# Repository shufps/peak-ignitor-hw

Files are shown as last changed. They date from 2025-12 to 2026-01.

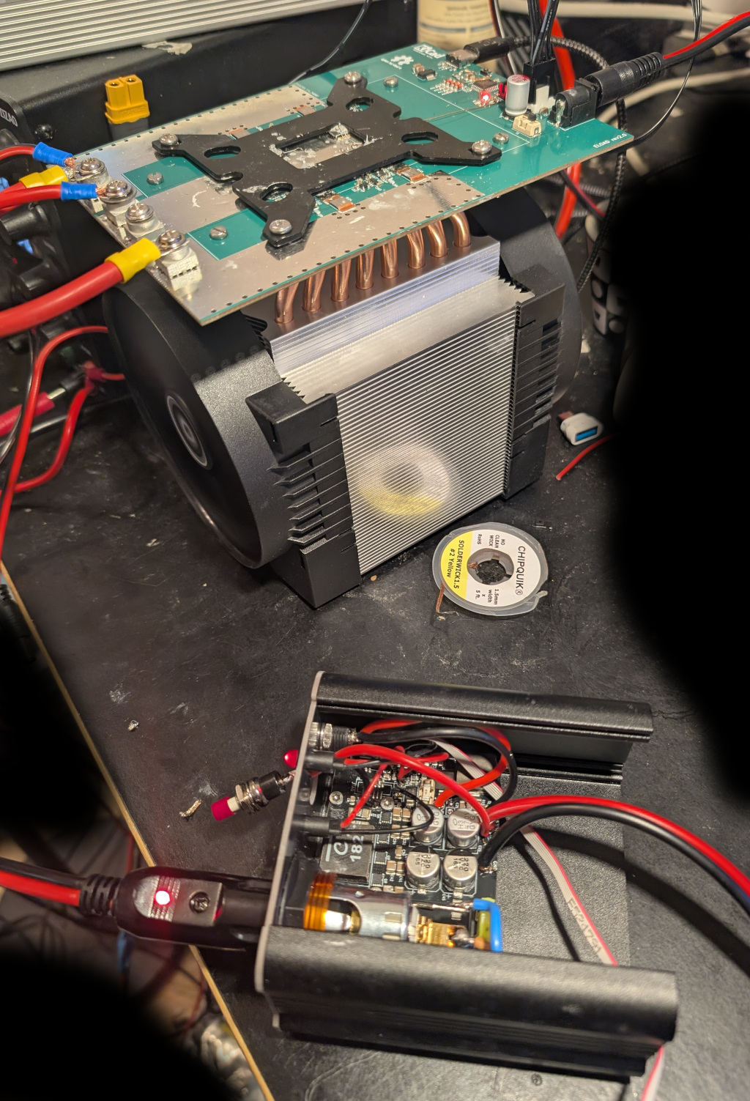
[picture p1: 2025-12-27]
images/load-test.jpg

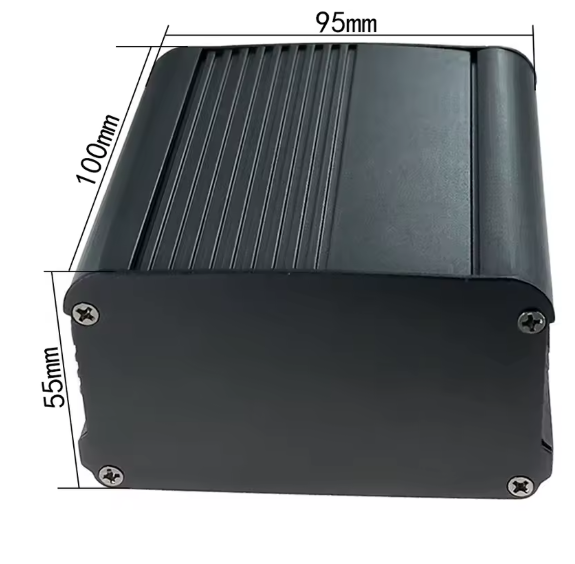
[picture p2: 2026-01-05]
bom/case.png

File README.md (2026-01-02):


> 🚧 **Work in Progress**  
> This project is under active development.

# 🔥 Peak Ignitor

**Peak Ignitor** is a compact, battery-powered **high-power 12 V supply** designed for one very specific real-world problem:

> *Reliable power in cold, wind, and harsh environments.*

The original trigger was simple:  
lighting a cigarette on a mountain at –10 °C and strong wind — where gas, electric, and plasma lighters all failed.

What *did* work was a classic **car cigarette lighter**:  
wind-proof, temperature-independent, and brutally simple — as long as you can supply enough current.

That requirement immediately defines the problem space:

- 6–10 A at 12 V  
- ~120 W continuous power  
- short but demanding duty cycles  

Peak Ignitor is the result.

---






## What It Is

Peak Ignitor is a **hand-sized, self-contained 12 V power unit** capable of delivering **120 W continuously** (up to ~160 W peak), powered by a **4S Li-Ion battery pack** and designed with **thermal and mechanical constraints as first-class design inputs**.

This is not a power bank and not a jump starter — it sits deliberately in between.

---

## Key Characteristics

- 🔋 **4S Li-Ion Battery System**
  - 4S1P Samsung 18650 (30Q)
  - ~44 Wh energy
  - Proper BMS with balancing and protection
  - Battery operated close to practical limits — intentionally and transparently

- ⚡ **Regulated 12 V Output**
  - High-power buck/boost converter (TI LM51770)
  - ~120 W continuous output
  - ~160 W peak, time-limited
  - Standard automotive cigarette lighter socket

- 🧊 **Mechanics-First Thermal Design**
  - Custom-machined **solid copper heatsink**
  - Direct thermal coupling into the aluminum enclosure
  - The enclosure itself acts as a secondary heatsink
  - Temperature measurement placed directly beneath the heatsink (TMP1075)

- 🧠 **Embedded Control & Monitoring**
  - ESP32-S3 Mini-1
  - Real-time monitoring of voltage, current, power, and temperature
  - Software-enforced safety limits (not just hardware ceilings)
  - Wi-Fi Web UI for observability (because why not 😎)

- 🔌 **Integrated Charging**
  - Onboard Li-Ion charging circuit
  - Balancer connector
  - Fully self-contained — no external hobby charger required

---

## Design Approach

A central idea behind Peak Ignitor is **mechanics-first design**:

The complete 3D model — enclosure, PCB outline, mounting points, heatsink geometry, connector placement, and thermal paths — was created **before** PCB layout and component selection.

This tightly couples:

- Mechanical design  
- PCB layout and form factor  
- Thermal constraints  
- User interaction and front-panel layout  

into a single coherent system.

As a result, the PCB, heatsink, battery pack, and enclosure are not independent parts — they are **co-designed elements of one integrated structure**.

---

## Thermal Philosophy

Thermal management is not an accessory here.

Heat is transferred:
1. from the power electronics  
2. into a custom copper heatsink  
3. directly into the aluminum enclosure  

This effectively turns the entire case into an active thermal component — a design style commonly found in industrial or automotive hardware, but rarely in DIY projects.

Sustained output is **intentionally limited by battery temperature**, not by electronic capability.

---

## Typical Use Cases

- 🔥 **Car cigarette lighter**  
  6–10 A for seconds — trivial load.

- 🏄 **SUP pumps / small compressors**  
  ~110 W continuous at 12 V.

- ⛏️ **NerdQAxe++**  
  ~80 W mobile operation.

- 🔌 **General 12 V loads**  
  Measurement equipment, adapters, field hardware.

---

## What This Project Demonstrates

Peak Ignitor is less about lighting a cigarette — and more about showing what happens when:

- real-world requirements  
- harsh environmental constraints  
- and a refusal to accept “almost good enough”  

meet a **system-level engineering mindset**.

It combines:
- energy storage  
- power electronics  
- thermal engineering  
- mechanical design  
- embedded firmware  

into a compact, honest, high-power device.

---

## Notes

- High-current device — **not a toy**
- Use only suitable loads
- Do not bypass or modify protection mechanisms
- Never operate the battery without the BMS

---

> *A good horse jumps only as high as it needs to.*  
> **Peak Ignitor jumps higher — on purpose.**

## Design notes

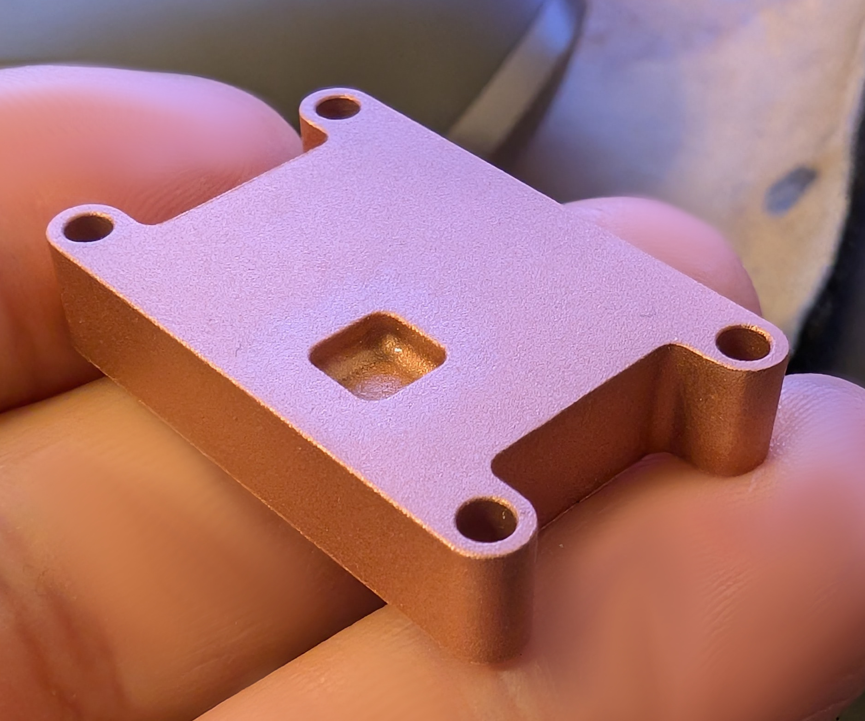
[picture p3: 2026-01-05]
images/heatsink.jpg

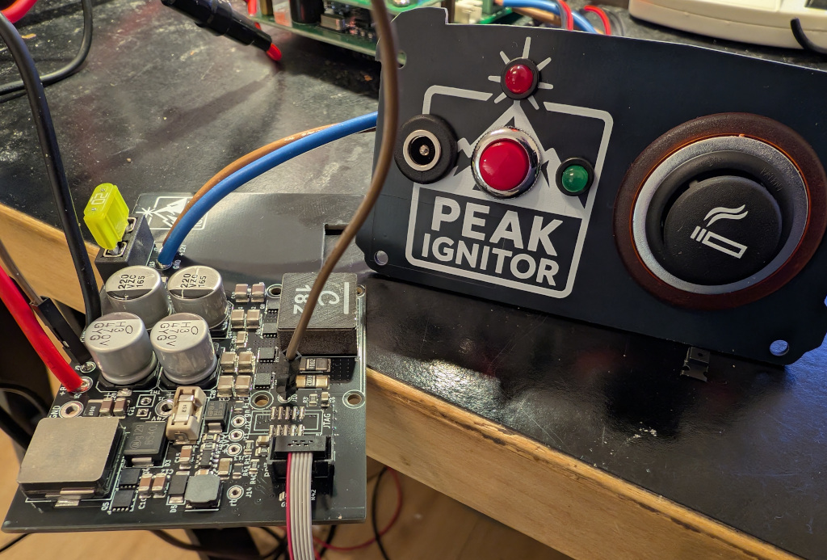
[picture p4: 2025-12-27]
images/pcb-top.jpg

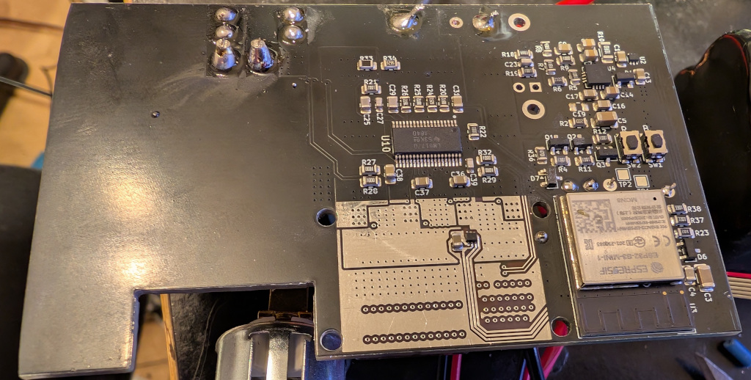
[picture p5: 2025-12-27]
images/pcb-bottom.jpg

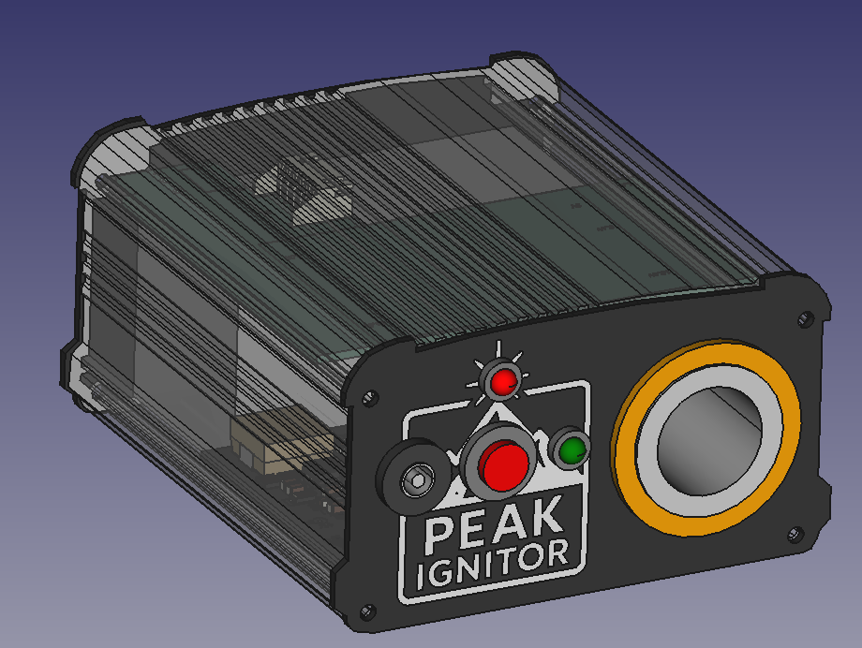
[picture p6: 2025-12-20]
images/case-3d-render.png

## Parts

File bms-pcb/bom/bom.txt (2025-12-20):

- XT30-PW-M (eg ebay)
- S5B-XH-A-1 (eg Aliexpress)
- BMS 4s PCB like in the picture

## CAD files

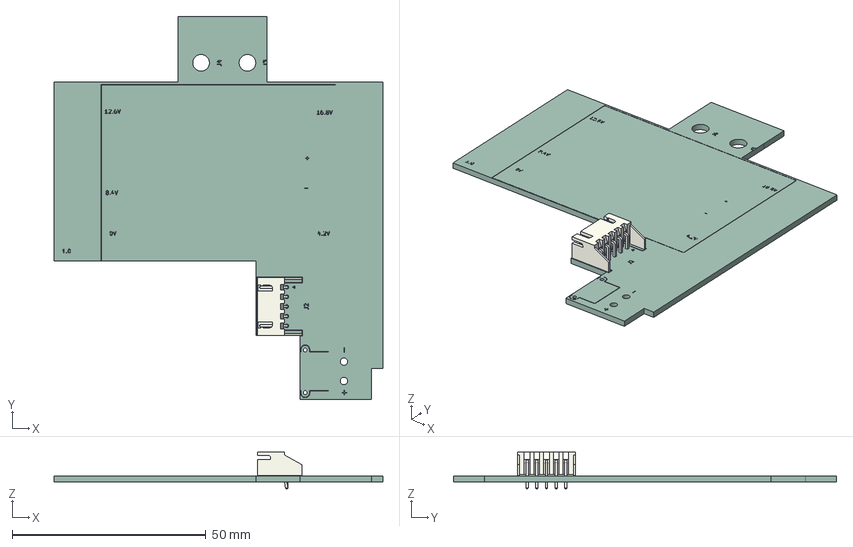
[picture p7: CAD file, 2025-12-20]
bms-pcb/kicad/peak-ignitor-box-bms.step
85.0 x 99.0 x 9.50 mm
JST_XH_S5B-XH-A-1_1x05_P2.50mm_Horizontal
peak-ignitor-box-bms_silkscreen
peak-ignitor-box-bms_PCB

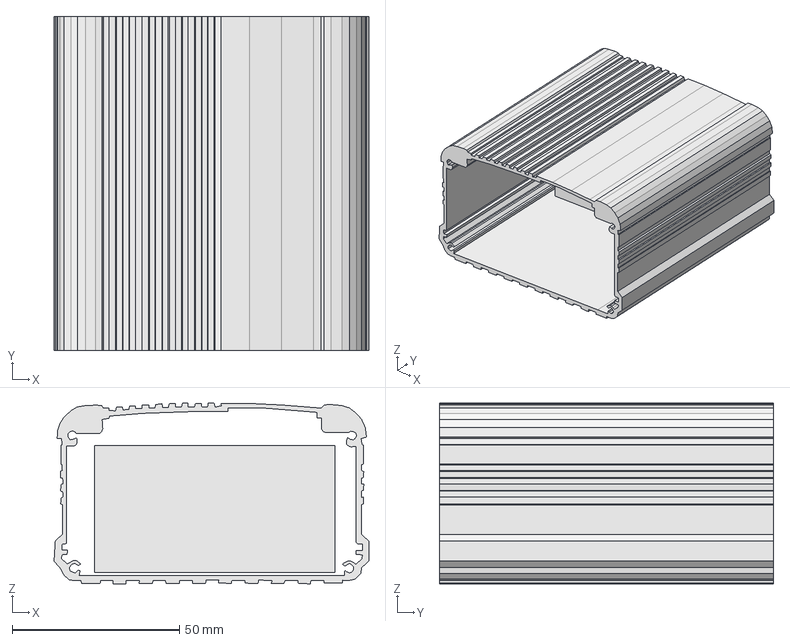
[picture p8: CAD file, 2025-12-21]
case/case.FCStd
94.3 x 100.0 x 54.2 mm

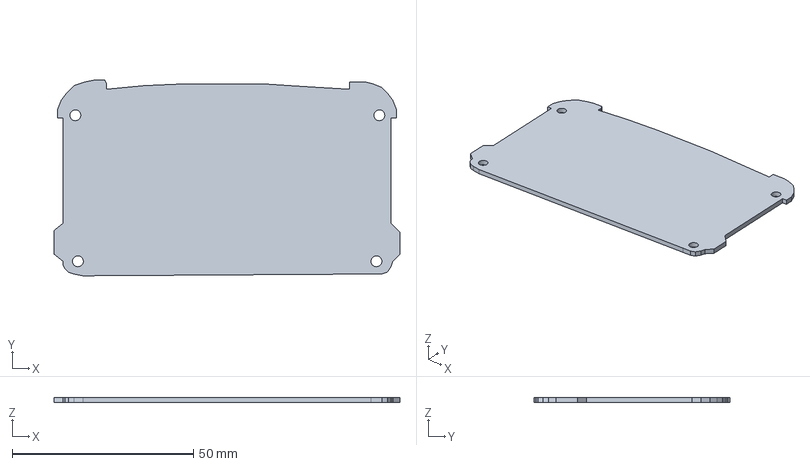
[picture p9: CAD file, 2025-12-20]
kicad/back.step
95.5 x 54.0 x 1.51 mm

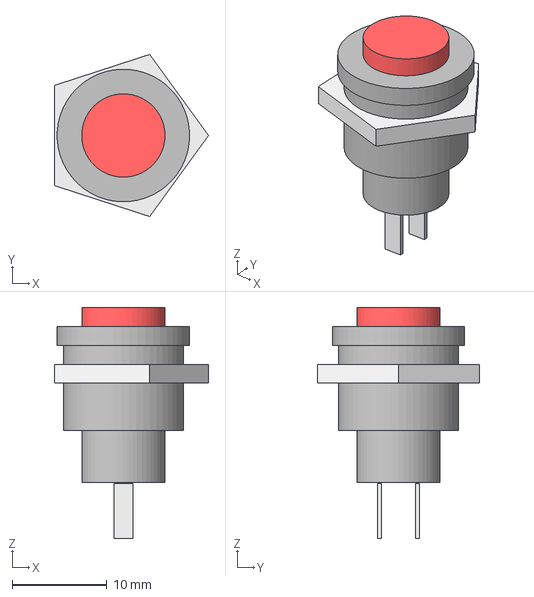
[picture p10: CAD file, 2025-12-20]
kicad/3d/switch.step
16.3 x 17.1 x 24.4 mm

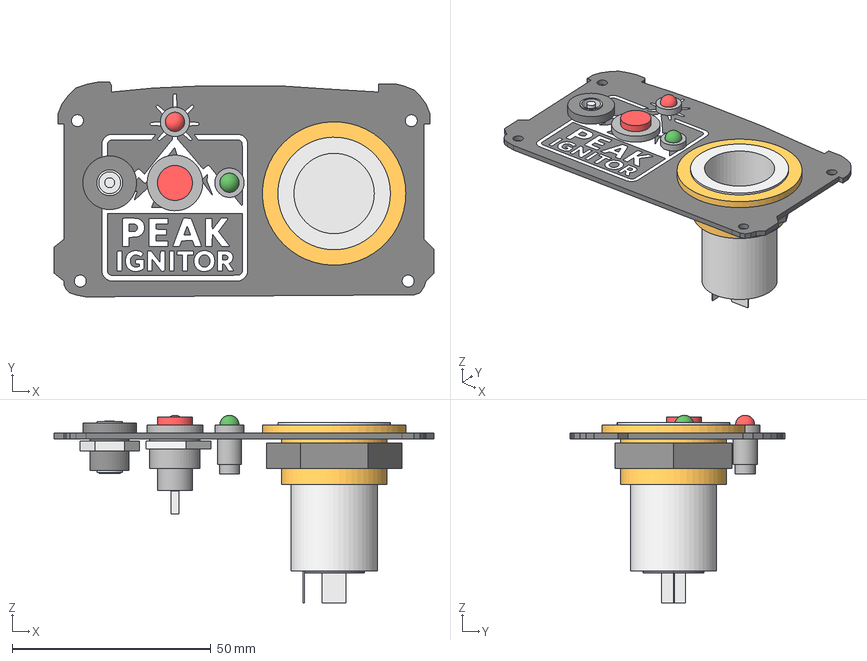
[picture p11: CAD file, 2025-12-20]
kicad/front.step
95.5 x 54.0 x 47.1 mm
led-red
led-green
switch
kfz2
barrel-jack
front_silkscreen
front_PCB

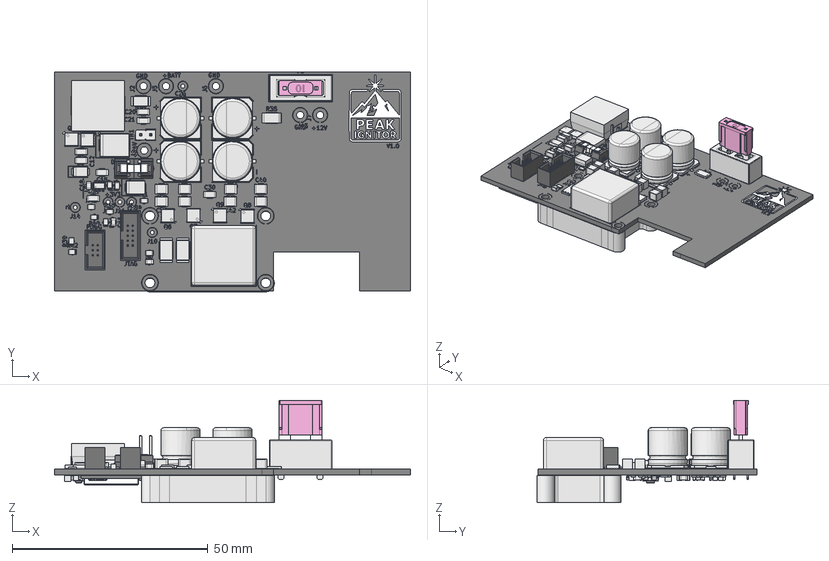
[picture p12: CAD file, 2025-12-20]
case/pcb.FCStd
91.0 x 56.2 x 26.1 mm
D_SMB
C_1206_3216Metric
R_2010_5025Metric
C_1206_3216Metric001
D_SMC
IND50X50FD
IND50X50FD001
IND50X50FD002
C_1206_3216Metric002
C_1206_3216Metric003
R_0805_2012Metric
PinHeader_1x02_P2.54mm_Vertical
C_1210_3225Metric
D_SOD-128
VSON-8_3.3x3.3mm_P0.65mm_NexFET
R_0805_2012Metric001
Fuseholder_Blade_Mini_Keystone_3568
C_1210_3225Metric001
C_0805_2012Metric
C_1206_3216Metric004
heatsink
CP_Elec_10x10.5
R_0805_2012Metric002
Fuse - mini 10A
Fuse - mini 10A001
C_0805_2012Metric001
C_1206_3216Metric005
R_0805_2012Metric003
R_2010_5025Metric001
VSON-8_3.3x3.3mm_P0.65mm_NexFET001
CP_Elec_10x10.006
R_2512_6332Metric
C_0805_2012Metric002
R_0805_2012Metric004
Komponente1
Komponente002
Komponente2
Komponente004
Komponente3
Komponente006
Komponente4
Komponente008
R_0805_2012Metric005
VSON-8_3.3x3.3mm_P0.65mm_NexFET002
C_1210_3225Metric002
C_1210_3225Metric003
R_2512_6332Metric001
VSON-8_3.3x3.3mm_P0.65mm_NexFET003
VSON-8_3.3x3.3mm_P0.65mm_NexFET004
CP_Elec_10x10.007
R_0805_2012Metric006
IDC_1.27mm_2x3
IDC_1.27mm_2x004
IDC_1.27mm_2x005
IDC_1.27mm_2x006
IDC_1.27mm_2x007
IDC_1.27mm_2x008
IDC_1.27mm_2x009
IDC_1.27mm_2x5
IDC_1.27mm_2x011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

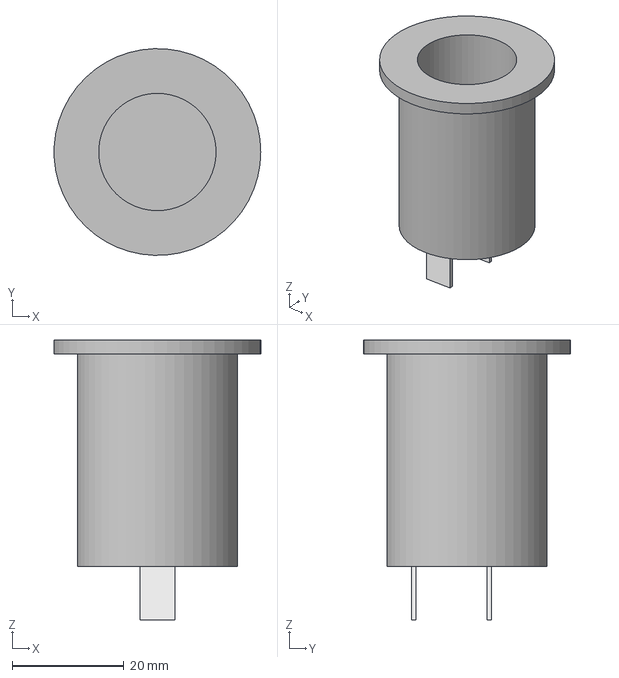
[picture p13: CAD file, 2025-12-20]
kicad/3d/krz.step
37.0 x 37.0 x 50.1 mm

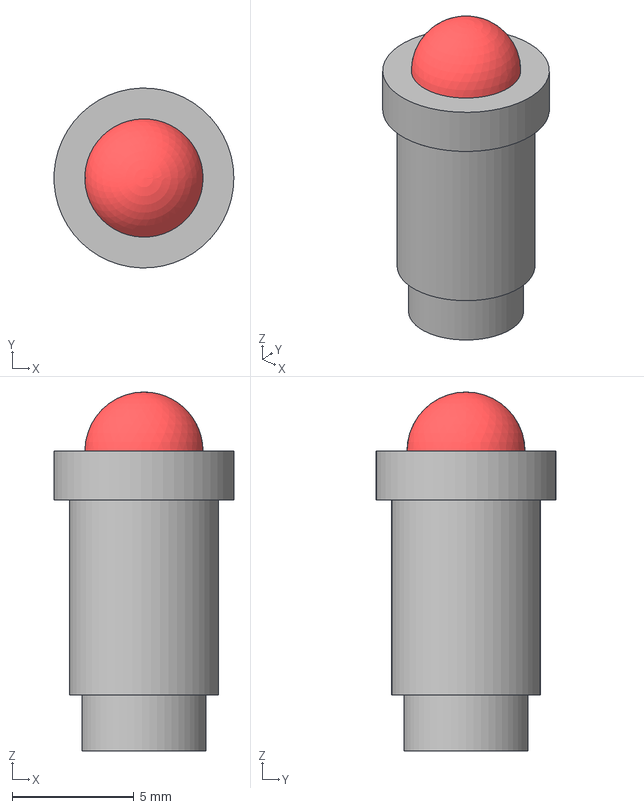
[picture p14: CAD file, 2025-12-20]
kicad/3d/led-red.step
7.37 x 7.38 x 14.7 mm

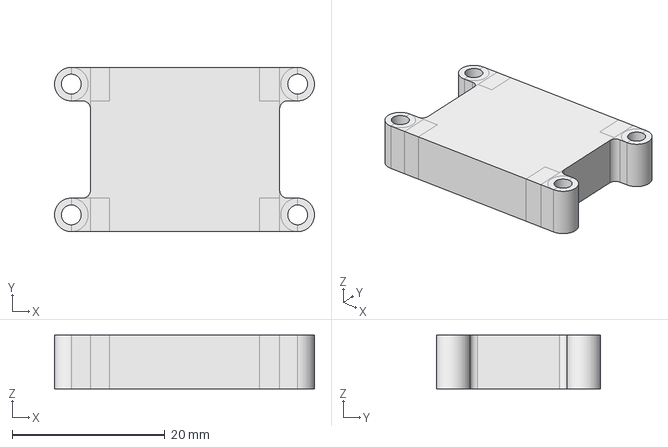
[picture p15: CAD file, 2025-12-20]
case/heatsink.FCStd
34.0 x 21.5 x 7.00 mm

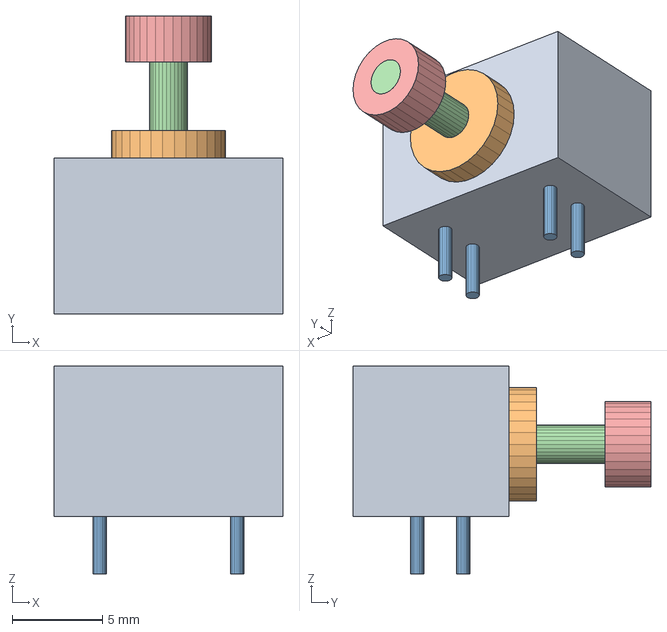
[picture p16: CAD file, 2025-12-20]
kicad/3d/39-261 RED.step
12.7 x 16.5 x 11.5 mm

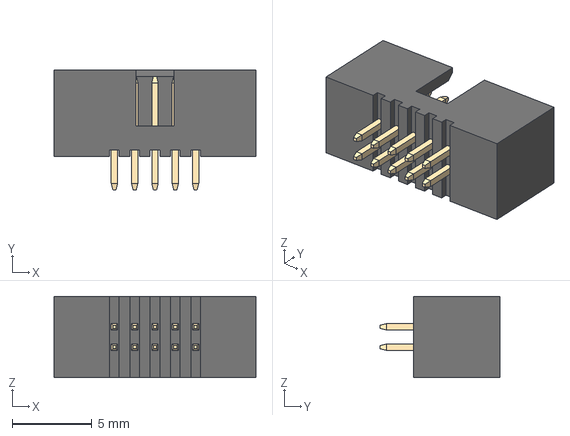
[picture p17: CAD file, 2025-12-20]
kicad/3d/IDC_1.27mm_2x5.step
12.6 x 7.50 x 5.10 mm

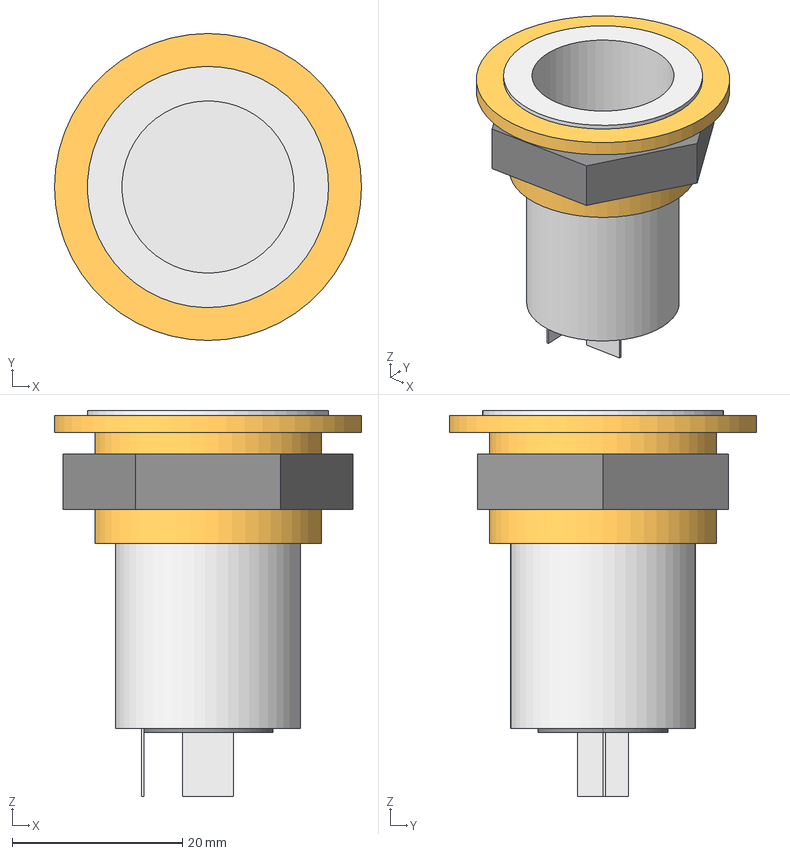
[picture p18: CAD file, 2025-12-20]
kicad/3d/kfz2.step
36.0 x 36.0 x 45.3 mm

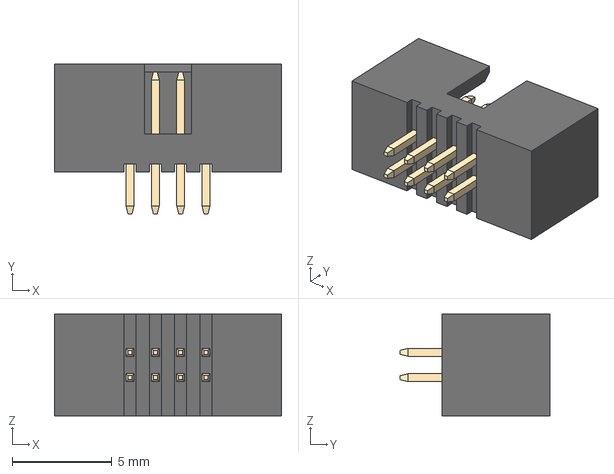
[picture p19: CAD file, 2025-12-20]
kicad/3d/IDC_1.27mm_2x4.step
11.4 x 7.50 x 5.10 mm

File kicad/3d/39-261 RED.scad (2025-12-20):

$fn=30;

translate([-12.7/2,-8.64,0]) cube([12.7, 8.64, 8.33], center=false);
translate([0,6.35+(10.16-8.64),4]) rotate([90,0,0]) cylinder(d=2.13, h=6.35+(10.16-8.64));
translate([0,6.35+(10.16-8.64),4]) rotate([90,0,0]) cylinder(d=4.75, h=2.54);
translate([0,6.35+(10.16-8.64)-6.35,4]) rotate([90,0,0]) cylinder(d=6.35, h=(10.16-8.64));

translate([-7.62/2,-2.54,0]) cylinder(d=0.76, h=3.18*2, center=true);
translate([7.62/2,-2.54,0]) cylinder(d=0.76, h=3.18*2, center=true);

translate([-7.62/2,-2*2.54,0]) cylinder(d=0.76, h=3.18*2, center=true);
translate([7.62/2,-2*2.54,0]) cylinder(d=0.76, h=3.18*2, center=true);

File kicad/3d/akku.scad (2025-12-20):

$fn=60;

color("#808080") cube([38,38,72]);

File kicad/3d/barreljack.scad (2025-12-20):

$fn=60;

 {
    difference() {
        union() {
            color("#404040") cylinder(d=13.5, h=2.5);
            color("#404040") difference() {
                translate([0,0,-9.5]) cylinder(d=11, h=9.5);
                translate([(9.8/2),-10,-9.6]) cube([20, 20, 9.5]);
                translate([-(9.8/2)-20,-10,-9.6]) cube([20, 20, 9.5]);
                
            }
            color("lightgray") translate([0,0,-2.5-2]) cylinder(d=15, h=2.5, $fn=6);
            color("lightgray") translate([0,0,-10]) cylinder(d=6.5, h=12.9);
        }
        translate([0,0,-7]) cylinder(d=5.5, h=10);
    }
    color("lightgray") translate([0,0,-7]) cylinder(d=2.5, h=10);
    color("#404040") translate([0,0,-10.2]) cylinder(d=5.5, h=1);
}



//cylinder(d=)

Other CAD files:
case/back.FCStd
case/bms.FCStd
case/front.FCStd
kicad/3d/led-green.step
kicad/3d/heatsink.step
kicad/3d/battery.scad
kicad/3d/3mm_LED.stp
kicad/3d/Fuse - mini 10A.iges
kicad/3d/Fuse - mini 10A.step
kicad/3d/IDC_1.27mm.f3d
kicad/3d/IDC_1.27mm_2x3.step
kicad/3d/IND50X50FD.step
kicad/3d/LM51770DCPR.stp
kicad/3d/Littelfuse 0154.500DRT without value_black v2.step
kicad/3d/RP3502MBRED.scad
kicad/3d/SSF-LXH400HGW.scad
kicad/3d/SSF-LXH400HGW.step
kicad/3d/SSF-LXH400HGW.stl
kicad/3d/barrel-jack.step
kicad/3d/heatsink.scad
kicad/3d/kfz-buchse.scad
kicad/3d/kfz2.scad
kicad/3d/led-green.scad
kicad/3d/led4_rtgn.scad
kicad/3d/led4_rtgn.stl

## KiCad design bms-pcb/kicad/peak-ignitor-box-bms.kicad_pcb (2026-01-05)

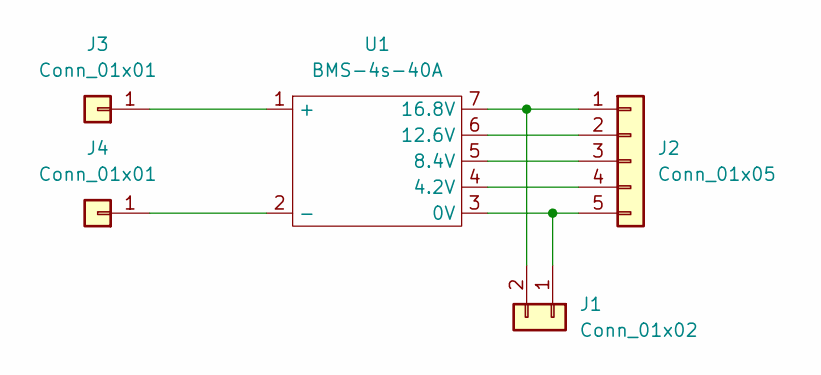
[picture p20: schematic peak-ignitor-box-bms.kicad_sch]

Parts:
J1: Conn_01x02; AMASS_XT30PW-M_1x02_P2.50mm_Horizontal
J2: Conn_01x05; JST_XH_S5B-XH-A-1_1x05_P2.50mm_Horizontal
J3, J4: Conn_01x01; MountingHole_4.3mm_M4_DIN965_Pad
U1: BMS-4s-40A; bms-4s-40A

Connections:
unnamed: J1.1, J2.5, U1.3 (0V)
unnamed: J1.2, J2.1, U1.7 (16.8V)
unnamed: J2.2, U1.6 (12.6V)
unnamed: J2.3, U1.5 (8.4V)
unnamed: J2.4, U1.4 (4.2V)
unnamed: J3.1, U1.1 (+)
unnamed: J4.1, U1.2 (-)

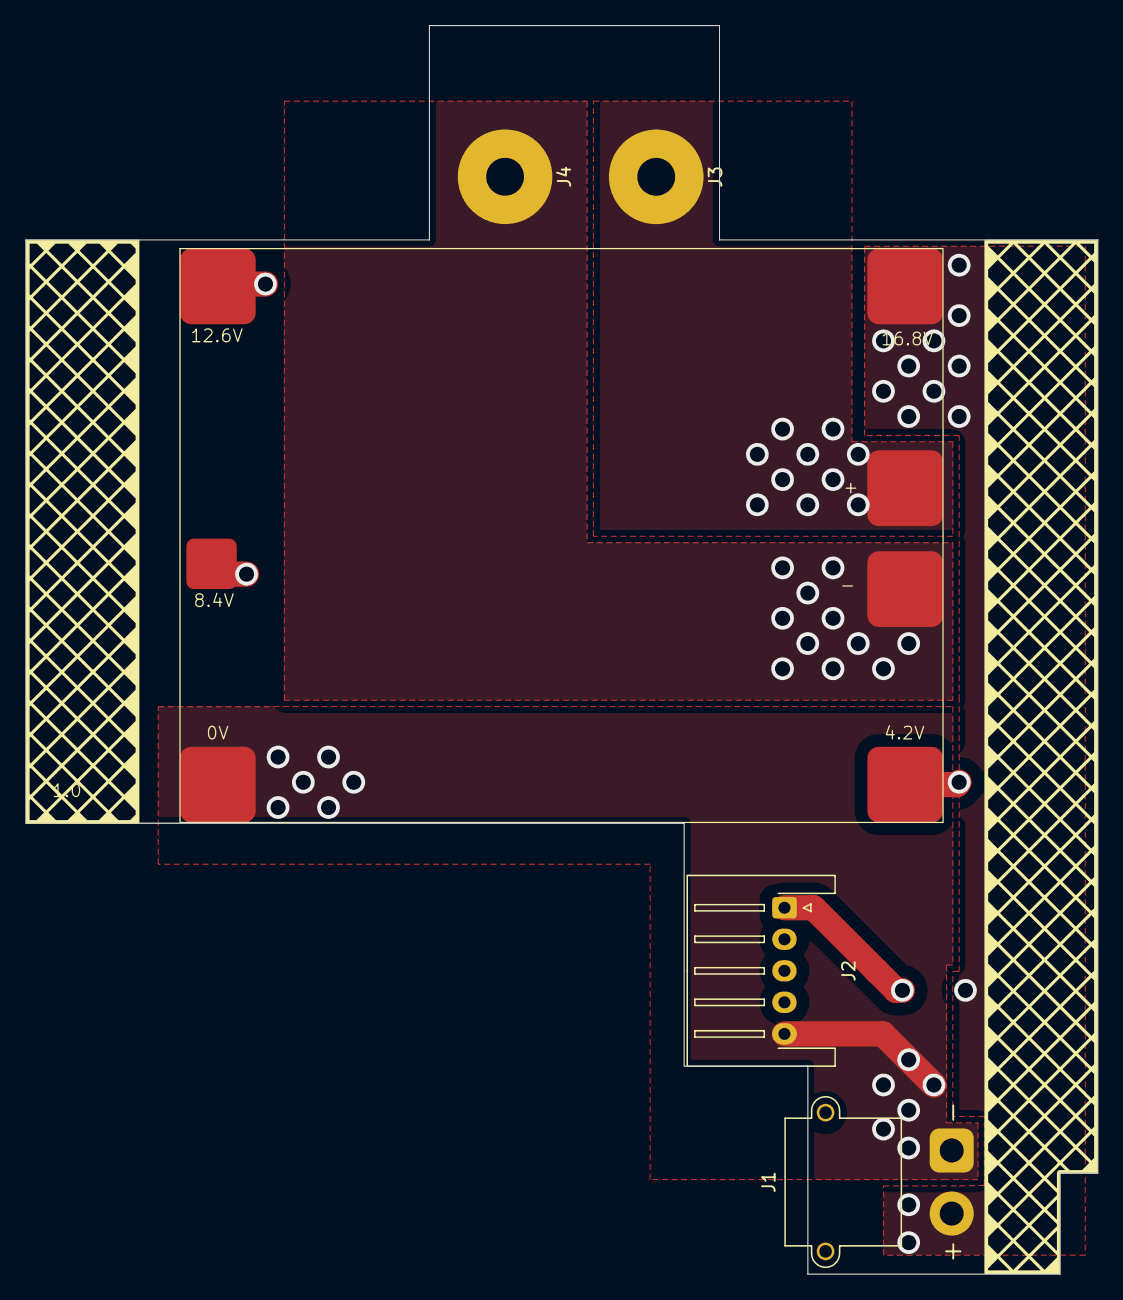
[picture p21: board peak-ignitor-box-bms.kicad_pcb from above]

Board: 4 copper layers, 85.0 x 99.0 mm, 5 parts (0 on the bottom side), 7 nets.

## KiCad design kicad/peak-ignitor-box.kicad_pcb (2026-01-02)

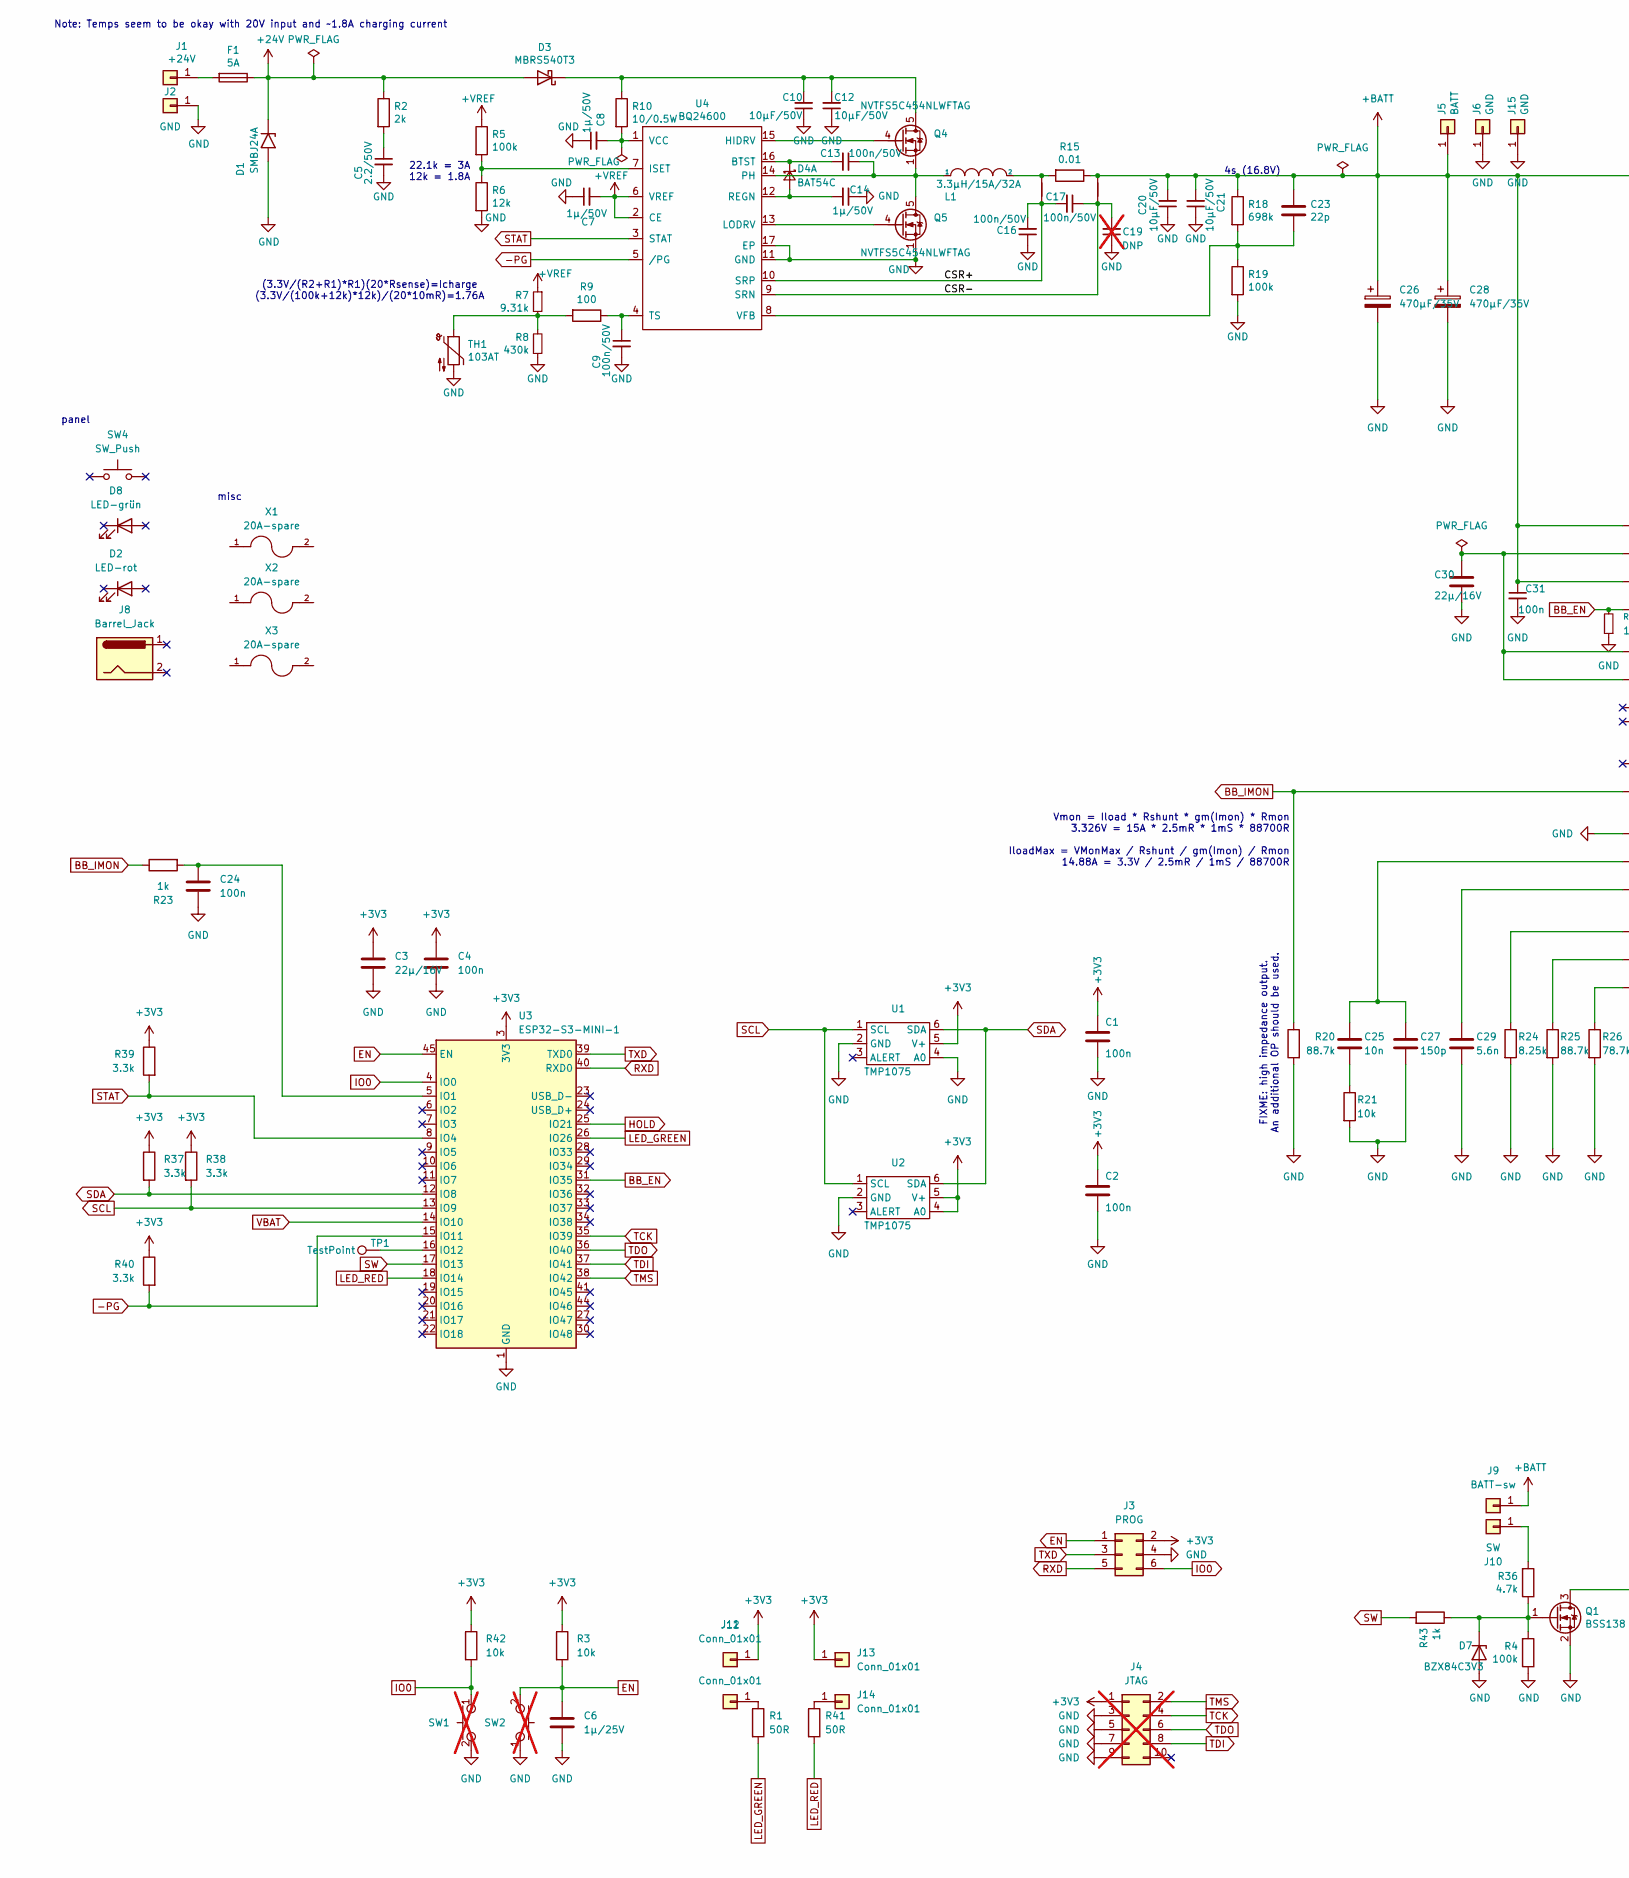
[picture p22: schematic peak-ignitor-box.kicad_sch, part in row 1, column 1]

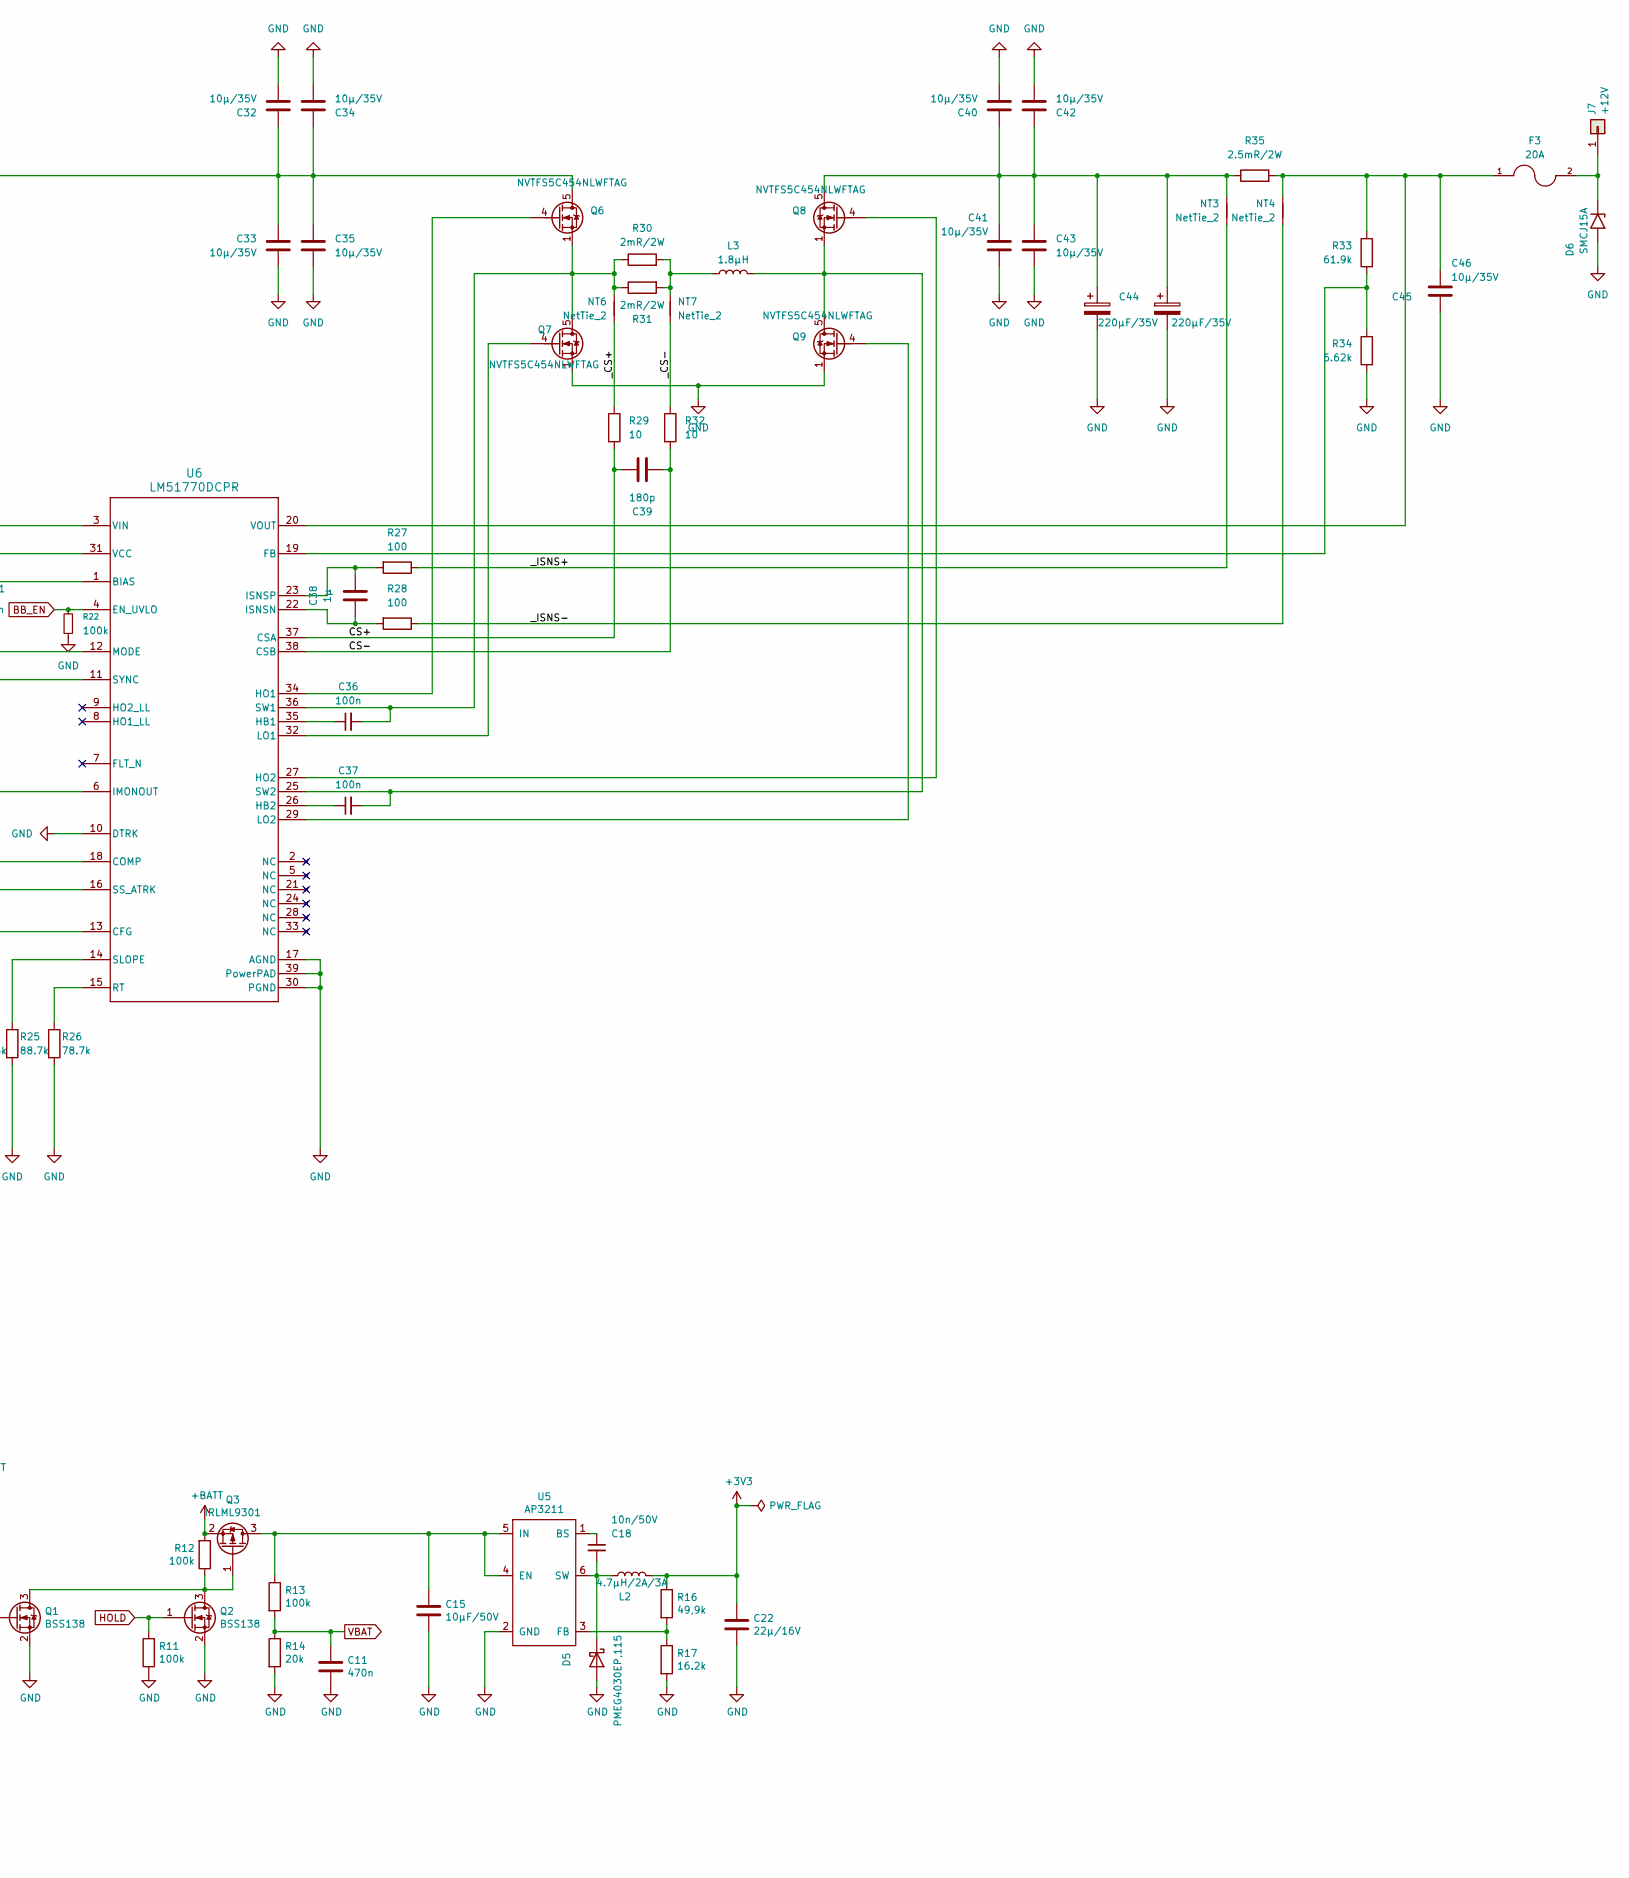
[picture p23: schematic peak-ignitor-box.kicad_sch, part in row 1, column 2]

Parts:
C1, C2, C4, C24, C31, C36, C37: 100n; C_0805_2012Metric
C3, C22, C30: 22µ/16V; C_1206_3216Metric
C5: 2.2/50V; C_1206_3216Metric
C6: 1µ/25V; C_0805_2012Metric; PARTNO EMK105BJ105MV-F
C7, C8, C14: 1µ/50V; C_0805_2012Metric
C9, C13, C16, C17: 100n/50V; C_0805_2012Metric
C10, C12, C15, C20, C21: 10µF/50V; C_1206_3216Metric
C11: 470n; C_0805_2012Metric
C18: 10n/50V; C_0805_2012Metric
C19: DNP; C_0805_2012Metric; not fitted
C23: 22p; C_0603_1608Metric
C25: 10n; C_0805_2012Metric
C26, C28: 470µF/35V; CP_Elec_10x10.5
C27: 150p; C_0603_1608Metric
C29: 5.6n; C_0805_2012Metric
C32, C33, C34, C35, C40, C41, C42, C43, C46: 10µ/35V; C_1210_3225Metric
C38: 1µ; C_0805_2012Metric
C39: 180p; C_0603_1608Metric
C44, C45: 220µF/35V; CP_Elec_10x10.5
D1: SMBJ24A; D_SMB
D2: LED-rot
D3: MBRS540T3; D_SMC
D4: BAT54C; SOT-23
D5: PMEG4030EP,115; D_SOD-128
D6: SMCJ15A; D_SMC
D7: BZX84C3V3; SOT-23
D8: LED-grün
F1: 5A; fuseholder_littlefuse_blok
F3: 20A; Fuseholder_Blade_Mini_Keystone_3568
J1: +24V; TestPoint_Loop_D2.50mm_Drill1.85mm
J2, J6, J15: GND; TestPoint_Loop_D2.50mm_Drill1.85mm
J3: PROG; PinHeader_IDC_2x03_P1.27mm_Vertical_SMD
J4: JTAG; PinHeader_IDC_2x05_P1.27mm_Vertical_SMD; not fitted
J5: BATT; TestPoint_Loop_D2.50mm_Drill1.85mm
J7: +12V; TestPoint_Loop_D2.50mm_Drill1.85mm
J8: Barrel_Jack
J9: BATT-sw; Pin_D1.0mm_L10.0mm
J10: SW; Pin_D1.0mm_L10.0mm
J11, J12, J13, J14: Conn_01x01; Pin_D1.0mm_L10.0mm
L1: 3.3µH/15A/32A; L_Vishay_IHLP-5050
L2: 4.7µH/2A/3A; L_Taiyo-Yuden_NR-50xx
L3: 1.8µH; L_Coilcraft_XAL1580-182
NT1, NT2: Net-Tie_2; NetTie-2_SMD_Pad0.5mm
NT3, NT4, NT6, NT7: NetTie_2; NetTie-2_SMD_Pad0.5mm
Q1, Q2: BSS138; SOT-23
Q3: IRLML9301; SOT-23
Q4, Q5, Q6, Q7, Q8, Q9: NVTFS5C454NLWFTAG; VSON-8_3.3x3.3mm_P0.65mm_NexFET
R1, R41: 50R; R_0805_2012Metric
R2: 2k; R_0805_2012Metric
R3, R21, R42: 10k; R_0805_2012Metric
R4, R5, R11, R12, R13, R19, R22: 100k; R_0805_2012Metric
R6: 12k; R_0805_2012Metric
R7: 9.31k; R_0805_2012Metric
R8: 430k; R_0805_2012Metric
R9, R27, R28: 100; R_0805_2012Metric
R10: 10/0.5W; R_1206_3216Metric
R14: 20k; R_0805_2012Metric
R15: 0.01; R_2010_5025Metric
R16: 49,9k; R_0805_2012Metric
R17: 16.2k; R_0805_2012Metric
R18: 698k; R_0805_2012Metric
R20, R25: 88.7k; R_0805_2012Metric
R23, R43: 1k; R_0805_2012Metric
R24: 8.25k; R_0805_2012Metric
R26: 78.7k; R_0805_2012Metric
R29, R32: 10; R_0805_2012Metric
R30, R31: 2mR/2W; R_2512_6332Metric
R33: 61.9k; R_0805_2012Metric
R34: 5.62k; R_0805_2012Metric
R35: 2.5mR/2W; R_2010_5025Metric
R36: 4.7k; R_0805_2012Metric
R37, R38, R39, R40: 3.3k; R_0805_2012Metric
SW1, SW2: GT-TC029B-H025-L1N; SW_Push_1P1T_NO_CK_KMR2; not fitted
SW4: SW_Push
TH1: 103AT; PinHeader_1x02_P2.54mm_Vertical
TP1: TestPoint; TestPoint_Pad_1.5x1.5mm
U1, U2: TMP1075; TMP1075-DRL
U3: ESP32-S3-MINI-1; ESP32-S2-MINI-1
U4: BQ24600; QFN-16-1EP_3.5x3.5mm_P0.5mm_EP2.14x2.14mm
U5: AP3211; SOT-23-6
U6: LM51770DCPR; DCP0038A-IPC_A
X1, X2, X3: 20A-spare

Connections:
+3V3: C1.1, C2.1, C3.1, C4.1, C22.1, J3.2, J4.1, J11.1, J13.1, L2.2, R3.1, R16.1, R37.1, R38.1, R39.1, R40.1, R42.1, U1.5 (V+), U2.4 (A0), U2.5 (V+), U3.3 (3V3)
+24V: D1.1 (A1), D3.2 (A), F1.1, R2.1
+BATT: C20.2, C21.2, C23.1, C26.1, C28.1, C31.1, C32.1, C33.1, C34.1, C35.1, J5.1, J9.1, NT2.2, Q3.2 (S), Q6.5 (D), R12.2, R15.1, R18.1, U6.1 (BIAS), U6.3 (VIN)
+VREF: C7.2, R5.1, R7.1, U4.2 (CE), U4.6 (VREF)
-PG: R40.2, U3.15 (IO11), U4.5 (/PG)
/CS+: C39.2, R29.2, U6.37 (CSA)
/CS-: C39.1, R32.2, U6.38 (CSB)
/CSR+: C16.2, C17.2, NT1.1, U4.10 (SRP)
/CSR-: C17.1, C19.2, NT2.1, U4.9 (SRN)
/_CS+: NT6.1, R29.1
/_CS-: NT7.1, R32.1
/_ISNS+: NT3.1, R27.1
/_ISNS-: NT4.1, R28.1
BB_EN: R22.2, U3.31 (IO35), U6.4 (EN_UVLO)
BB_IMON: R20.1, R23.1, U6.6 (IMONOUT)
EN: C6.1, J3.1, R3.2, SW2.2, U3.45 (EN)
GND: C1.2, C2.2, C3.2, C4.2, C5.2, C6.2, C7.1, C8.1, C9.2, C10.1, C11.2, C12.1, C14.1, C15.2, C16.1, C19.1, C20.1, C21.1, C22.2, C24.2, C26.2, C27.2, C28.2, C29.2, C30.2, C31.2, C32.2, C33.2, C34.2, C35.2, C40.2, C41.2, C42.2, C43.2, C44.2, C45.2, C46.2, D1.2 (A2), D5.2 (A), D6.2 (A2), D7.1 (A), J2.1, J3.4, J4.3, J4.5, J4.7, J4.9, J6.1, J15.1, Q1.2 (S), Q2.2 (S), Q5.1 (S), Q5.2 (S), Q5.3 (S), Q7.1 (S), Q7.2 (S), Q7.3 (S), Q9.1 (S), Q9.2 (S), Q9.3 (S), R4.1, R6.2, R8.1, R11.1, R14.2, R17.2, R19.2, R20.2, R21.2, R22.1, R24.2, R25.2, R26.2, R34.2, SW1.2, SW2.1, TH1.2, U1.2 (GND), U1.4 (A0), U2.2 (GND), U3.1 (GND), U3.2 (GND), U3.42 (GND), U3.43 (GND), U3.46 (GND), U3.47 (GND), U3.48 (GND), U3.49 (GND), U3.50 (GND), U3.51 (GND), U3.52 (GND), U3.53 (GND), U3.54 (GND), U3.55 (GND), U3.56 (GND), U3.57 (GND), U3.58 (GND), U3.59 (GND), U3.60 (GND), U3.61 (GND), U3.62 (GND), U3.63 (GND), U3.64 (GND), U3.65 (GND), U4.11 (GND), U4.17 (EP), U5.2 (GND), U6.10 (DTRK), U6.17 (AGND), U6.30 (PGND), U6.39 (PowerPAD)
HOLD: Q2.1 (G), R11.2, U3.25 (IO21)
IO0: J3.6, R42.2, SW1.1, U3.4 (IO0)
LED_GREEN: R1.2, U3.26 (IO26)
LED_RED: R41.2, U3.18 (IO14)
unnamed: C5.1, R2.2
unnamed: C25.2, R21.1
unnamed: C10.2, C12.2, D3.1 (K), Q4.5 (D), R10.1
unnamed: C14.2, D4.1 (A), U4.12 (REGN)
unnamed: C13.2, D4.3 (K), U4.16 (BTST)
unnamed: C18.2, D5.1 (K), L2.1, U5.6 (SW)
unnamed: D6.1 (A1), F3.2, J7.1
unnamed: D7.3 (K), Q1.1 (G), R4.2, R36.1, R43.1
unnamed: F1.2, J1.1
unnamed: J10.1, R36.2
unnamed: J12.1, R1.1
unnamed: J14.1, R41.1
unnamed: L1.2, NT1.2, R15.2
unnamed: L3.1, NT7.2, R30.2, R31.2
unnamed: Q1.3 (D), Q2.3 (D), Q3.1 (G), R12.1
unnamed: C15.1, Q3.3 (D), R13.1, U5.4 (EN), U5.5 (IN)
unnamed: Q4.4 (G), U4.15 (HIDRV)
unnamed: C13.1, L1.1, Q4.1 (S), Q4.2 (S), Q4.3 (S), Q5.5 (D), U4.14 (PH)
unnamed: Q5.4 (G), U4.13 (LODRV)
unnamed: Q6.4 (G), U6.34 (HO1)
unnamed: C36.2, NT6.2, Q6.1 (S), Q6.2 (S), Q6.3 (S), Q7.5 (D), R30.1, R31.1, U6.36 (SW1)
unnamed: Q7.4 (G), U6.32 (LO1)
unnamed: C40.1, C41.1, C42.1, C43.1, C44.1, C45.1, NT3.2, Q8.5 (D), R35.1
unnamed: Q8.4 (G), U6.27 (HO2)
unnamed: C37.2, L3.2, Q8.1 (S), Q8.2 (S), Q8.3 (S), Q9.5 (D), U6.25 (SW2)
unnamed: Q9.4 (G), U6.29 (LO2)
unnamed: R7.2, R8.2, R9.2, TH1.1
unnamed: C24.1, R23.2, U3.5 (IO1)
unnamed: TP1.1, U3.16 (IO12)
unnamed: R5.2, R6.1, U4.7 (ISET)
unnamed: C9.1, R9.1, U4.4 (TS)
unnamed: C8.2, R10.2, U4.1 (VCC)
unnamed: C23.2, R18.2, R19.1, U4.8 (VFB)
unnamed: C18.1, U5.1 (BS)
unnamed: R16.2, R17.1, U5.3 (FB)
unnamed: R24.1, U6.13 (CFG)
unnamed: C25.1, C27.1, U6.18 (COMP)
unnamed: R33.2, R34.1, U6.19 (FB)
unnamed: C36.1, U6.35 (HB1)
unnamed: C37.1, U6.26 (HB2)
unnamed: C38.1, R28.2, U6.22 (ISNSN)
unnamed: C38.2, R27.2, U6.23 (ISNSP)
unnamed: C30.1, U6.11 (SYNC), U6.12 (MODE), U6.31 (VCC)
unnamed: R26.1, U6.15 (RT)
unnamed: R25.1, U6.14 (SLOPE)
unnamed: C29.1, U6.16 (SS_ATRK)
unnamed: C46.1, F3.1, NT4.2, R33.1, R35.2, U6.20 (VOUT)
RXD: J3.5, U3.40 (RXD0)
SCL: R38.2, U1.1 (SCL), U2.1 (SCL), U3.13 (IO9)
SDA: R37.2, U1.6 (SDA), U2.6 (SDA), U3.12 (IO8)
STAT: R39.2, U3.8 (IO4), U4.3 (STAT)
SW: R43.2, U3.17 (IO13)
TCK: J4.4, U3.35 (IO39)
TDI: J4.8, U3.37 (IO41)
TDO: J4.6, U3.36 (IO40)
TMS: J4.2, U3.38 (IO42)
TXD: J3.3, U3.39 (TXD0)
VBAT: C11.1, R13.2, R14.1, U3.14 (IO10)

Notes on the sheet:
Note: Temps seem to be okay with 20V input and ~1.8A charging current
(3.3V/(R2+R1)*R1)(20*Rsense)=Icharge (3.3V/(100k+12k)*12k)/(20*10mR)=1.76A
Vmon = Iload * Rshunt * gm(Imon) * Rmon 3.326V = 15A * 2.5mR * 1mS * 88700R IloadMax = VMonMax / Rshunt / gm(Imon) / Rmon 14.88A = 3.3V / 2.5mR / 1mS / 88700R
panel
FIXME: high impedance output. An additional OP should be used.
misc
22.1k = 3A 12k = 1.8A
4s (16.8V)

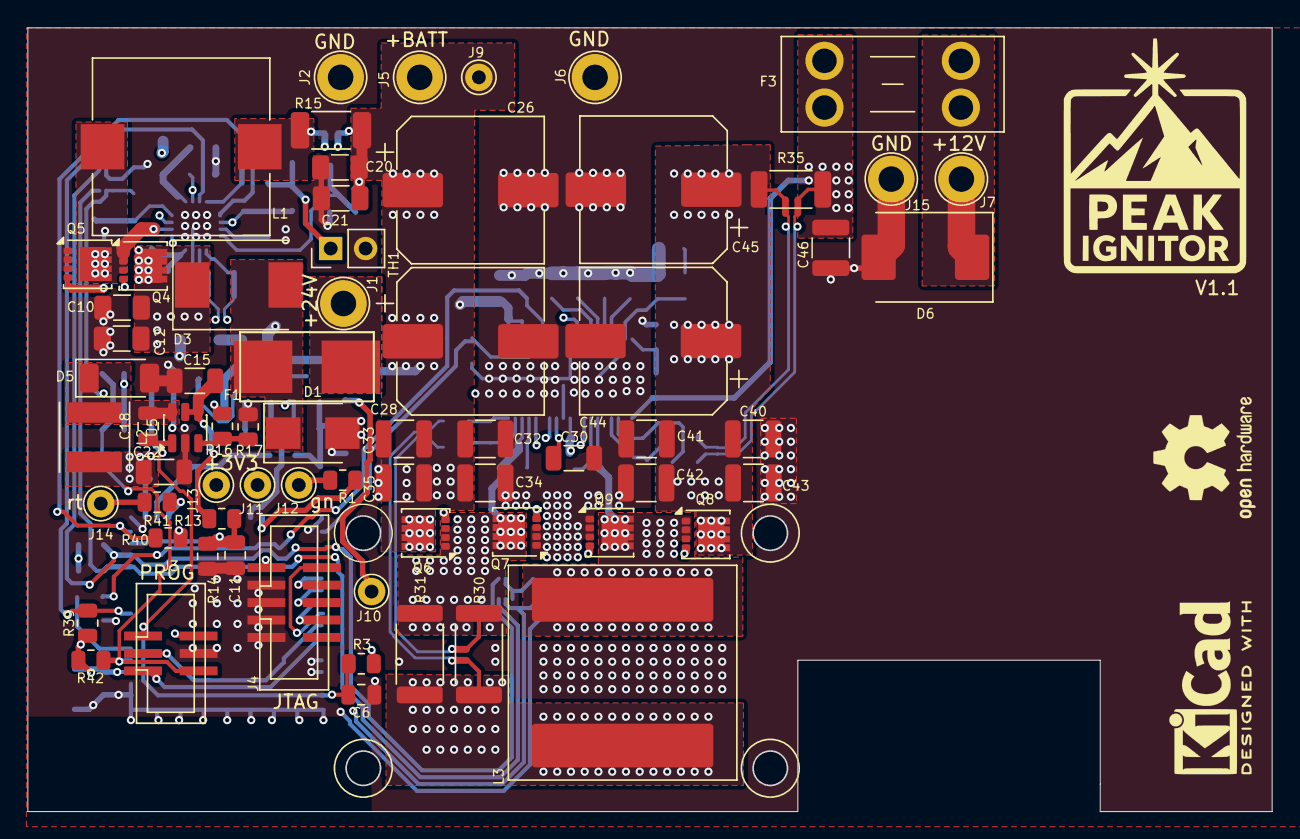
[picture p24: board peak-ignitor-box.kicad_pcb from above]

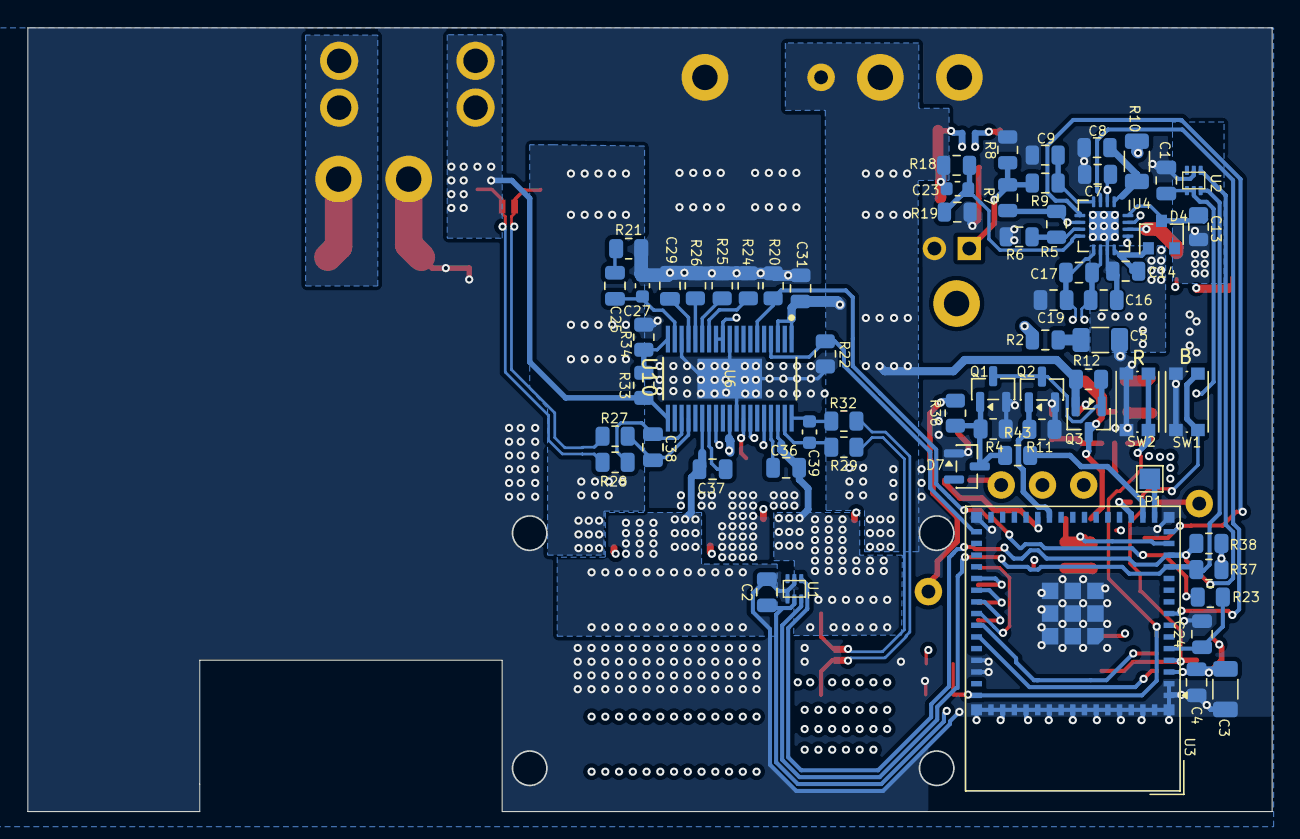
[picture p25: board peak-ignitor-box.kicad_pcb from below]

Board: 4 copper layers, 90.5 x 57.0 mm, 139 parts (67 on the bottom side), 79 nets.

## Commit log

2025-12-20 added all case files
    [back.FCStd, bms.FCStd, case.FCStd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]
2025-12-20 added gerbers
    [peak-ignitor-box-B_Cu.gbl, peak-ignitor-box-B_Mask.gbs, peak-ignitor-box-B_Paste.gbp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]
2025-12-20 moved a bit
    [peak-ignitor-box-bms-B_Cu.gbl, peak-ignitor-box-bms-B_Mask.gbs, peak-ignitor-box-bms-B_Paste.gbp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]
2025-12-20 added li-ion battery
2025-12-20 bom for bms pcb
2025-12-21 added lm51770 step
    [LM51770DCPR.stp, case.FCStd, peak-ignitor-box.kicad_pcb]
2025-12-26 updated gerbers, bom, some bug fixes on schematic and board
    [peak-ignitor-box-B_Cu.gbl, peak-ignitor-box-B_Mask.gbs, peak-ignitor-box-B_Paste.gbp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]
2025-12-27 Update power specifications in README
2025-12-27 added plots for charge and 120W discharge
2025-12-29 added 160W discharge
    [peak-ignitor-box.kicad_pcb, peak-ignitor-box.kicad_sch]
2026-01-02 updated gerbers, bom, ibom
    [digikey.csv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]
2026-01-05 updated bms carrier
    [peak-ignitor-box-bms-B_Cu.gbl, peak-ignitor-box-bms-B_Mask.gbs, peak-ignitor-box-bms-B_Paste.gbp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]
